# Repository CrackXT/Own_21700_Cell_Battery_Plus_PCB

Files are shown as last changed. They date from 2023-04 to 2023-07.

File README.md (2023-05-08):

# Own_21700_Cell_Battery_Plus_PCB

PCB files for a 21700 cell mount on a separate board with protection circuit and battery fuel gauge.

# Description

Compatible with unprotected 21700 cell type only!

This is an external battery cell board that allows you to mount the appropriate cell holder (21700) and thus have better connection and mounting options in your project or case. This is the "plus" variant with protection circuit and a battery fuel gauge.

The board can be produced here (AISLER) with the files (.brd and .sch) or by any other PCB manufacturer. -> https://aisler.net/

# Serie

- .pro

# Layout

Top<br>
21700_Plus_Top_v1 1

Bottom<br>
21700_Plus_Bottom_v1 1

Routing/Dimensions(inch)<br>
21700_Plus_v1 1

Schematic<br>
Schematic as .pdf at the top of the page.

# License

Open hardware, use it, mod it, whatever you want, feel free...

# Thanks!

Own design and layout.

# Version - Build

v1.1 - 30.04.2023

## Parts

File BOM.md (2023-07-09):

# BOM - List

part list for Use

# cell holder
2x Keystone 247 (THT - Typ 21700) https://www.digikey.de/de/products/detail/keystone-electronics/247/11696838
 
# connector
1x JST-PH2 (THT - Axial) https://www.reichelt.de/jst-stiftleiste-gerade-1x2-polig-ph-jst-ph2p-st-p185049.html?&trstct=pos_11&nbc=1<br>
1x JST-SH4 (SMT - Axial) https://www.conrad.de/de/p/jst-stiftgehaeuse-platine-sh-polzahl-gesamt-4-rastermass-1-mm-bm04b-srss-tb-lf-sn-1-st-1426417.html<br>

# resistor
1x 330Ohm 0805 https://www.reichelt.de/smd-widerstand-0805-330-ohm-125-mw-0-1--spr-0805-330-p123233.html?&trstct=pol_2&nbc=1<br>
1x 470Ohm 0805 https://www.reichelt.de/smd-widerstand-0805-470-ohm-125-mw-0-1--spr-0805-470-p123238.html?&trstct=pol_3&nbc=1<br>
2x 10kOhm 0805 https://www.reichelt.de/smd-widerstand-0805-10-kohm-0-1-tk25-125-mw-spr-0805-10-0k-p123305.html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<br>

# capacitor
2x 0,1µF 0805 https://www.reichelt.de/dk/de/smd-vielschichtkondensator-g0805-1-0-f-25v-x7r-g0805-1-0-25-p89730.html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

# ic
1x MAX17048 TDFN https://www.digikey.de/de/products/detail/analog-devices-inc-maxim-integrated/MAX17048G-T10/3758921<br>
1x S-82M1AAA-I6T1U7 SNT-6A https://www.digikey.de/de/products/detail/ablic-inc/S-82M1AAA-I6T1U7/14664146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<br>

# mosfet
1x ECH8693R-TL-W SOT28 https://www.digikey.de/de/products/detail/onsemi/ECH8693R-TL-W/5257549?s=N4IgTCBcDaIKYGMAWAOAbATgMwCcQF0BfIA

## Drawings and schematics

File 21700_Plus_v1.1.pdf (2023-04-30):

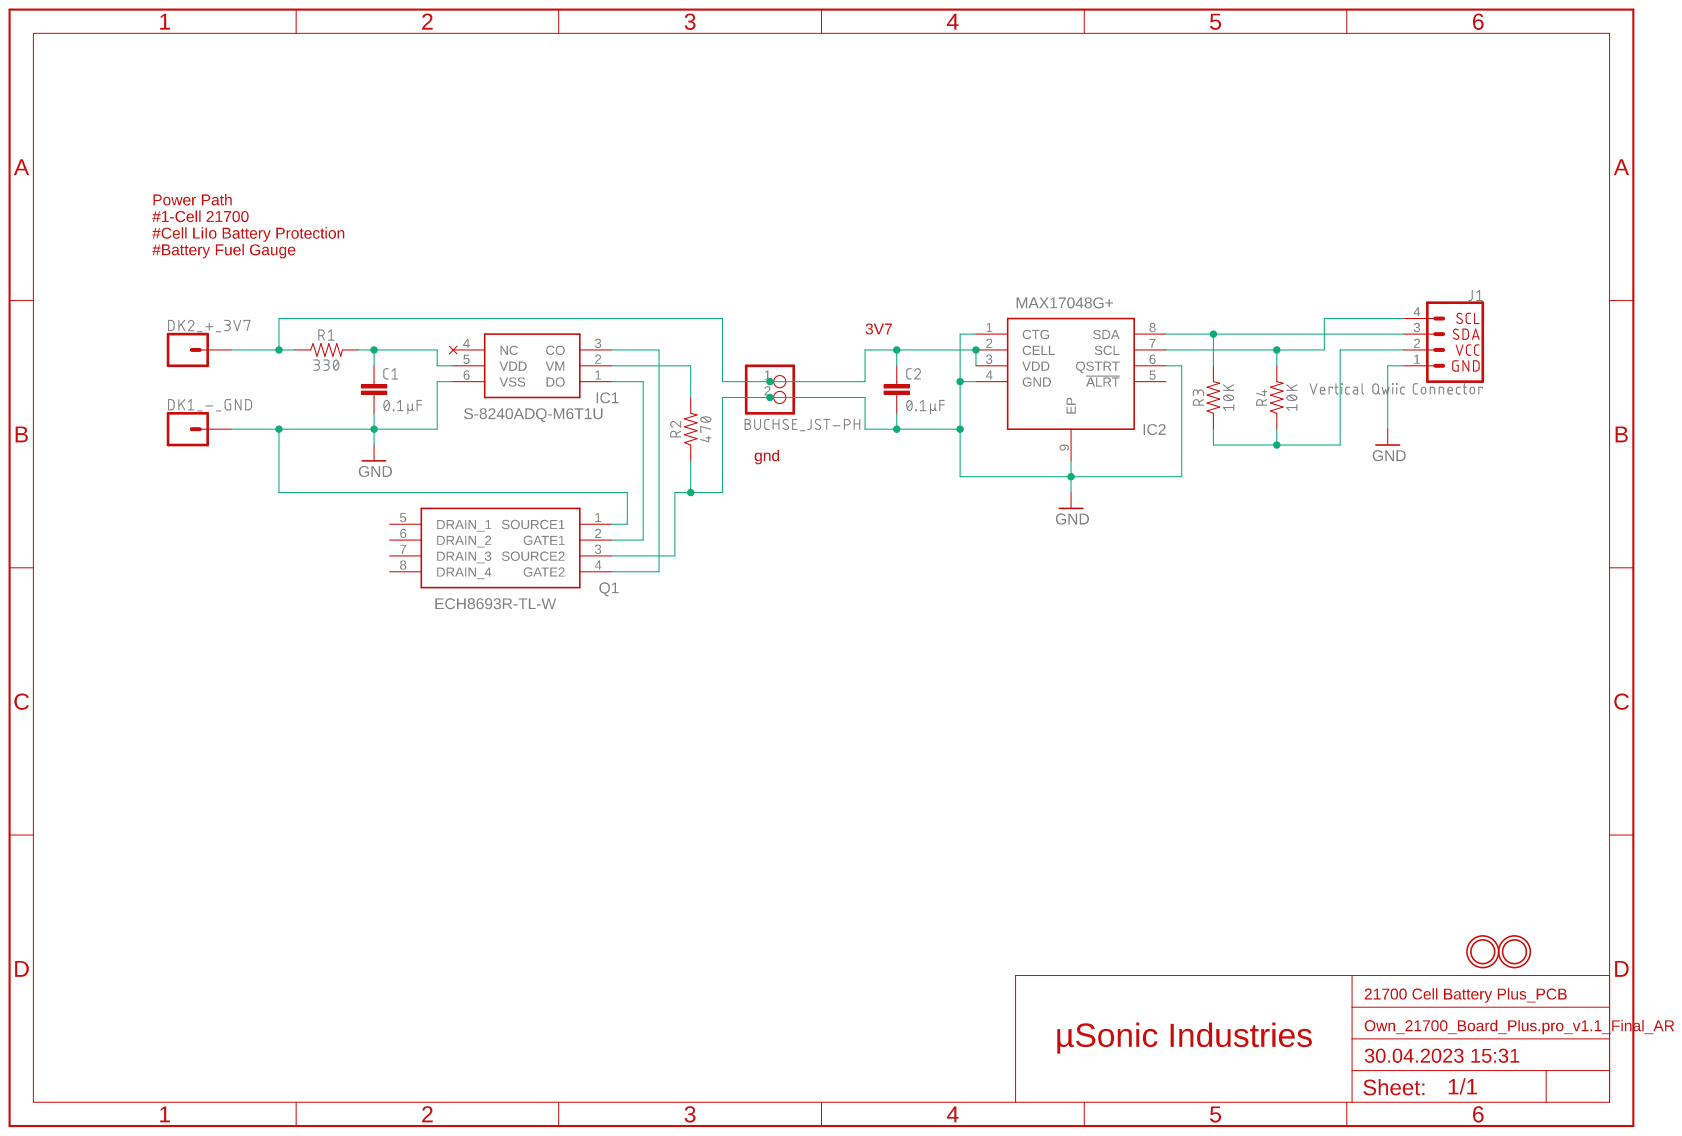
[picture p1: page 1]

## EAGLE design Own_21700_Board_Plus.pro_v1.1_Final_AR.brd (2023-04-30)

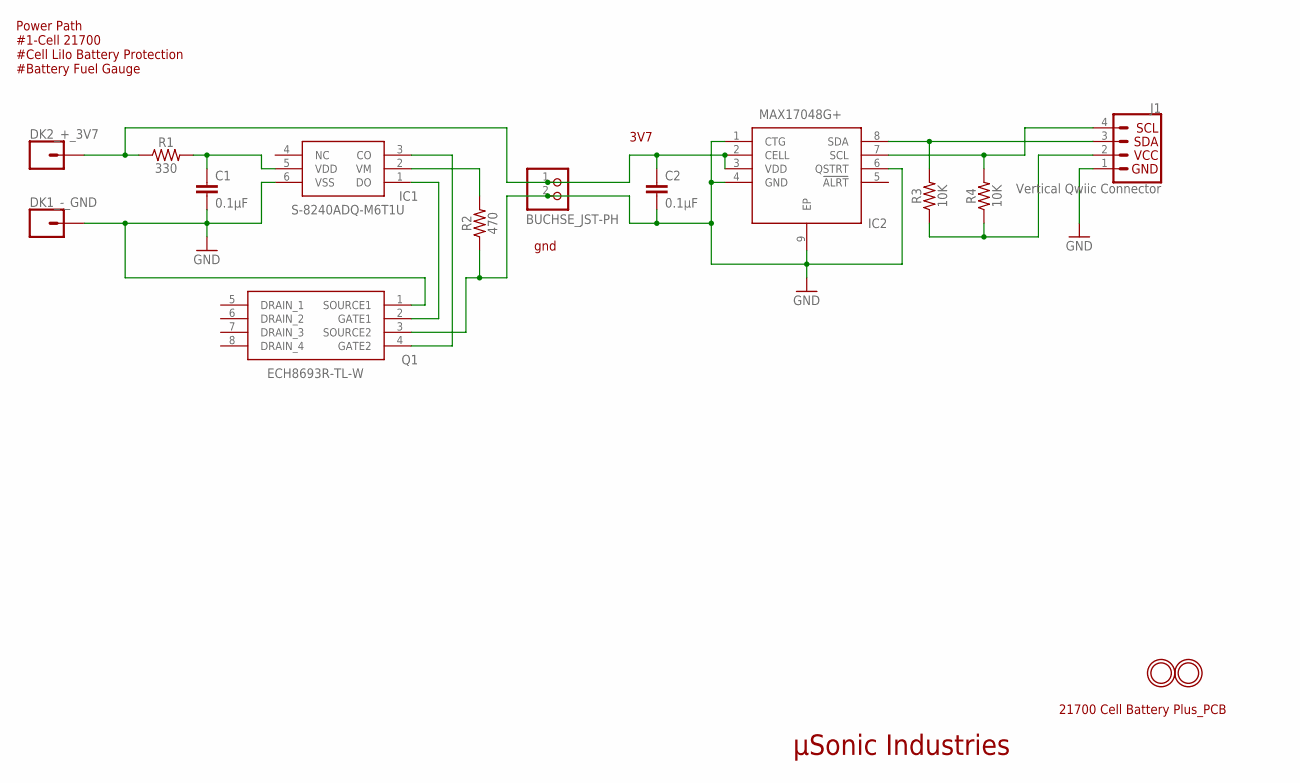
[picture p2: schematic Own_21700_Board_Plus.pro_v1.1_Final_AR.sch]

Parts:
BUCHSE_JST-PH: JST_2PINOWN; JST-PH-2-THMOWN
C1, C2: 0.1µF; 0805
DK1_-_GND, DK2_+_3V7: CONN_01PTH_2MM; 1X01_2MM
IC1: S-8240ADQ-M6T1U; SOT95P275X135-6N
IC2: MAX17048G+; SON50P200X200X80-9N
J1: Vertical Qwiic Connector; JST04_1MM_VERT
Q1: ECH8693R-TL-W; SOTFL65P280X95-8N
R1: 330; 0805
R2: 470; 0805
R3, R4: 10K; 0805
U$3, U$5: MOUNTINGHOLE2.5; MOUNTINGHOLE_2.5_PLATED

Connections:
3V3: J1.2, R3.1, R4.1
3V7: BUCHSE_JST-PH.1 (2), C2.1, DK2_+_3V7.1, IC2.2 (CELL), IC2.3 (VDD), R1.1
GATE1: IC1.1 (DO), Q1.2 (GATE1)
GATE2: IC1.3 (CO), Q1.4 (GATE2)
GND: BUCHSE_JST-PH.2 (1), C1.2, C2.2, DK1_-_GND.1, IC1.6 (VSS), IC2.1 (CTG), IC2.4 (GND), IC2.6 (QSTRT), IC2.9 (EP), J1.1, Q1.1 (SOURCE1), Q1.3 (SOURCE2), R2.1
unnamed: IC2.8 (SDA), J1.3, R3.2
unnamed: IC2.7 (SCL), J1.4, R4.2
VDD: C1.1, IC1.5 (VDD), R1.2
VM: IC1.2 (VM), R2.2

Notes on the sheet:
µSonic Industries
21700 Cell Battery Plus_PCB
Power Path #1-Cell 21700 #Cell LiIo Battery Protection #Battery Fuel Gauge
gnd
3V7

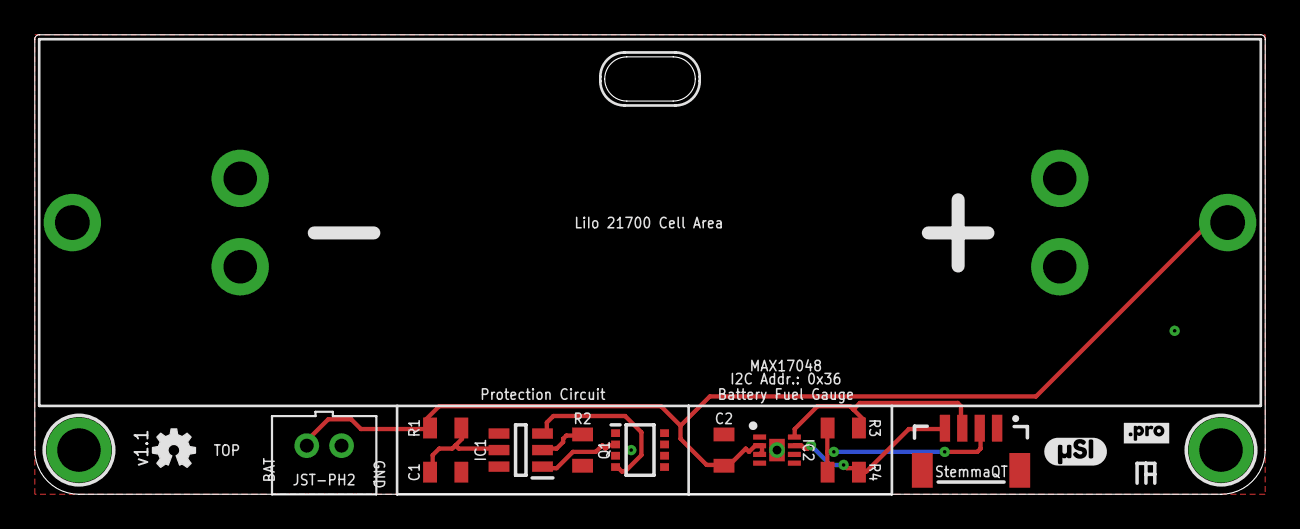
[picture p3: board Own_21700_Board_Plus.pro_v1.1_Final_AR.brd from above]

Board: 2 copper layers, 70.7 x 26.4 mm, 18 parts (0 on the bottom side), 9 nets.

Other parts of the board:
U$6: OSHW-LOGO-MINI
U$7: µSI2
U$8: PRO2

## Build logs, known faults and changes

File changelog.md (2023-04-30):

# Version - Build
v1.0 - 23.04.2023
- First Release

v1.1 - 30.04.2023
- Rename
- GND Fix

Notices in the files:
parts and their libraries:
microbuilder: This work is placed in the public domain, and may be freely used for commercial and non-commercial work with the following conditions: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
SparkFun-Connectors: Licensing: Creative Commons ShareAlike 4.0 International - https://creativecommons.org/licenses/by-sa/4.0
